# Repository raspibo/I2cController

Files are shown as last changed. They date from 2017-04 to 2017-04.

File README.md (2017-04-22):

# I2cController
Evolution of I2C_rotary_encoder, a board with lcd, rotary encoder, push buttons for general purpose input/output over I2C bus

Whit this board you can interact with a standard hardware equipment of rotary encoder, lcd display, push buttons over I2C, you can 
also mount a partial set of peripherals.

The code handle interrupt of pin change generated from MC23017 chip when event fire on buttons or rotary encoder.

# Use
Put portable dir under your arduino folder to use project specific libraries

# Typical Schematic



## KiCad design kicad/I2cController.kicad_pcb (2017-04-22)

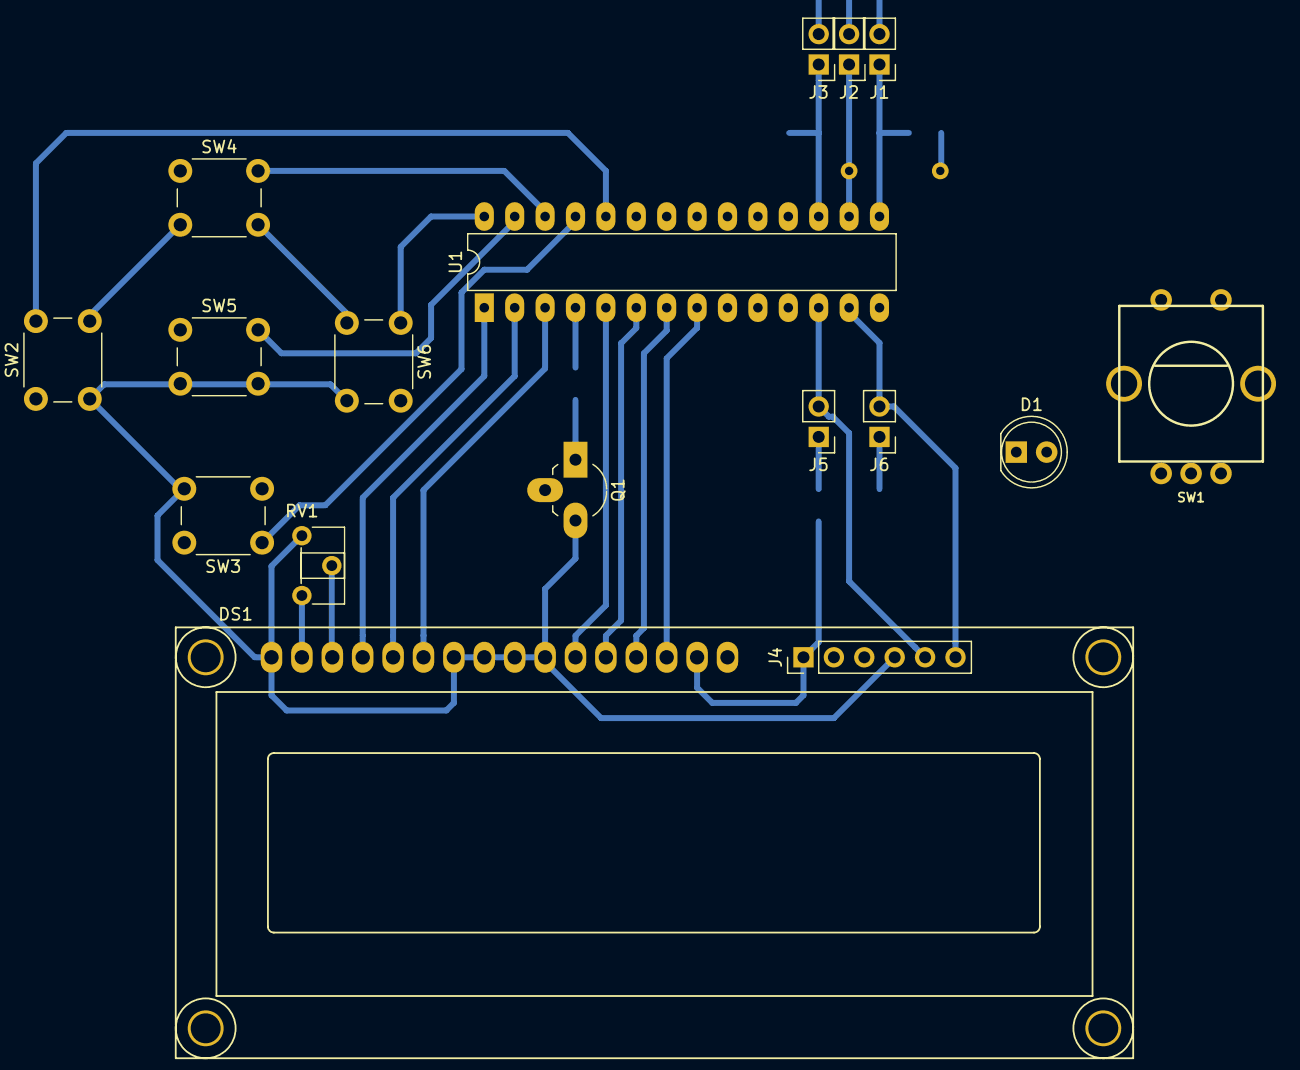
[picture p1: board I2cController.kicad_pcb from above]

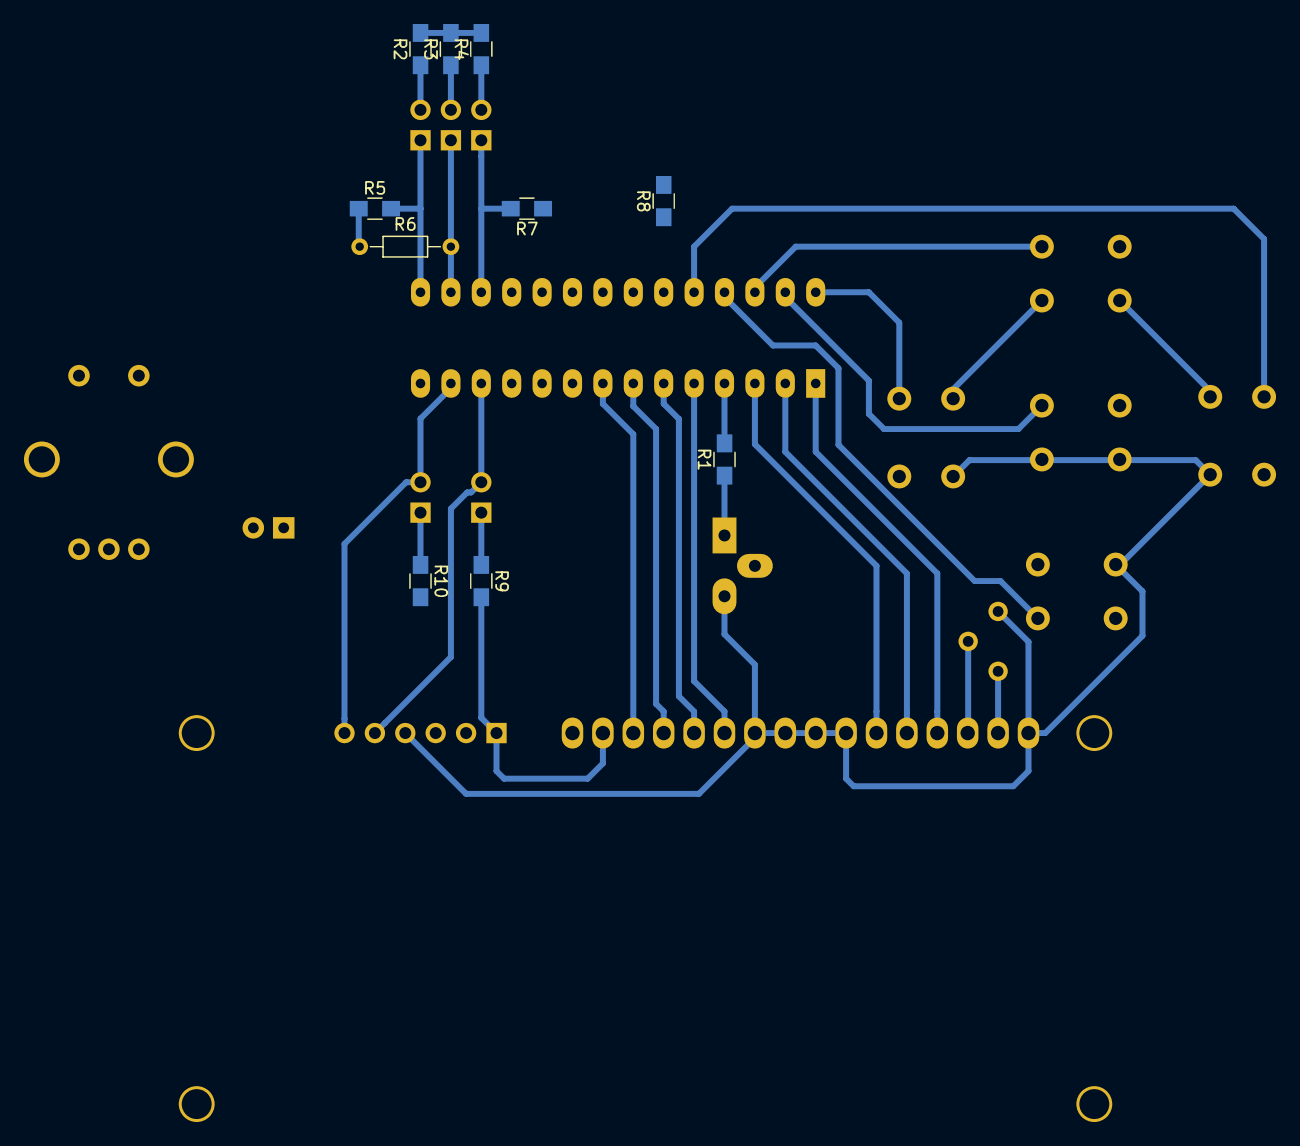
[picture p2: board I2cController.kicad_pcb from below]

Board: 2 copper layers, 27 parts (10 on the bottom side), 34 nets.

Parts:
D1: LED; LED_D5.0mm
DS1: LCD16X2; WC1602A
J1, J2, J3, J5, J6: CONN_02X01; Pin_Header_Straight_1x02_Pitch2.54mm
J4: CONN_01X06; Pin_Header_Straight_1x06_Pitch2.54mm
Q1: Q_NPN_BCE; TO-92_Rugged_Reverse
R1, R2, R3, R4, R5, R7, R8, R9, R10: R; R_0805_HandSoldering
R6: R; R_Axial_DIN0204_L3.6mm_D1.6mm_P7.62mm_Horizontal
RV1: POT; Potentiometer_Trimmer_ACP_CA6h_Vertical
SW1: Rotary_Encoder_Switch; SF-ROTARY-ENCODER
SW2, SW3, SW4, SW5, SW6: SW_Push; SW_PUSH_6mm_h7.3mm
U1: MCP23017; DIP-28_W7.62mm_LongPads

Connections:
GND: DS1.1, DS1.7, DS1.8, DS1.9, DS1.10, J4.4, Q1.3, R5.1, R6.1, R7.1, RV1.1, SW1.2, SW1.5, SW2.2, SW3.2, SW4.2, SW5.2, SW6.2, U1.10
L_D0: DS1.4, U1.1
L_D1: DS1.5, U1.2
L_D2: DS1.6, U1.3
L_D3: R1.2, U1.4
L_D4: DS1.11, U1.5
L_D5: DS1.12, U1.6
L_D6: DS1.13, U1.7
L_D7: DS1.14, U1.8
unnamed: D1.1, R8.1
unnamed: DS1.3, RV1.2
unnamed: DS1.16, Q1.2
unnamed: J1.1, R5.2, U1.15
unnamed: J1.2, R2.1
unnamed: J2.1, R6.2, U1.16
unnamed: J2.2, R3.1
unnamed: J3.1, R7.2, U1.17
unnamed: J3.2, R4.1
unnamed: J4.2, U1.18
unnamed: J4.3, R8.2, U1.20
unnamed: J5.1, R9.1
unnamed: J6.1, R10.1
unnamed: Q1.1, R1.1
unnamed: SW1.1, U1.22
unnamed: SW1.3, U1.21
unnamed: SW1.4, U1.23
unnamed: SW2.1, U1.24
unnamed: SW3.1, U1.25
unnamed: SW4.1, U1.26
unnamed: SW5.1, U1.27
unnamed: SW6.1, U1.28
SCL: J4.5, J5.2, U1.12
SDA: J4.6, J6.2, U1.13
VCC: D1.2, DS1.2, DS1.15, J4.1, R2.2, R3.2, R4.2, R9.2, R10.2, RV1.3, U1.9

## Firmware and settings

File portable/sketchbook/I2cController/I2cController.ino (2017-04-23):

/*
   From https://github.com/lincomatic/I2cControllerLib
   and http://blog.think3dprint3d.com/2012/12/mcp23017-i2c.html
 */

// include the library code:
#include <Wire.h>
#include <I2cController.h>

#define EN_A 0 // Encored scroll A0
#define EN_B 1 // Encoder scroll A1 
#define EN_C 2 // Encoder click  A2
#define BTN_NUM 5
#define BTN_1 3 // Single button A3
#define BTN_2 4 // Single button A4
#define BTN_3 5 // Single button A5
#define BTN_4 6 // Single button A6
#define BTN_5 7 // Single button A7

// Connect via i2c, default address #0 (A0-A2 not jumpered)
I2cControllerLib contr(0);
int encoderPos=0;
uint8_t clickButton;

uint8_t Pot;
char ActEnc, OldEnc;


// Interrupts from the MCP will be handled by this PIN on Arduino
byte arduinoIntPin = 3;
// ... and this interrupt vector
byte arduinoInterrupt = 1;

volatile boolean awakenByInterrupt = false;
unsigned long lastMillisInterrupt = 0;

void handleInterrupt() {

	detachInterrupt(arduinoInterrupt);
	if (millis()>lastMillisInterrupt+25) {
		//A    |¯¯|__|¯¯|__|¯
		//B  - __|¯¯|__|¯¯|__  +
		// Nel canale A pin D3 condensatore ceramico 103K 10nF
		uint8_t ActEnc=0;
		uint8_t intPin=contr.getLastInterruptPin();
		uint8_t valPin=contr.getLastInterruptPinValue();
		//Serial.print("intPin: ");
		//Serial.println(intPin);
		//Switch che  decide come gestire interrupt in base al pin che lo ha generato se A0 o A1 interpreta encoder altrimenti interpretazione come pulsante
		switch(intPin) {
			case EN_A:
			case EN_B:
				bitWrite(ActEnc, 0,contr.digitalRead(EN_A));
				bitWrite(ActEnc, 1,contr.digitalRead(EN_B));
				switch(ActEnc) {
					case 0: //00
						if(OldEnc==2) Pot++;  //10
						if(OldEnc==1) Pot--;  //01
						break;
					case 1: //01
						if(OldEnc==0) Pot++;  //00
						if(OldEnc==3) Pot--;  //11
						break;
					case 2: //10
						if(OldEnc==3) Pot++;  //11
						if(OldEnc==0) Pot--;  //00
						break;
					case 3: // 11
						if(OldEnc==1) Pot++;  //01
						if(OldEnc==2) Pot--;  //10
						break;
				}
				OldEnc=ActEnc;
				Serial.print("Pot: ");
				Serial.println(Pot);
				break;
			case EN_C:
				Serial.println("click");
				break;
			default:
				Serial.print("Button: A");
				Serial.println(intPin);
				break;
		}
	}



	lastMillisInterrupt=millis();
	cleanInterrupts();
	//we set callback for the arduino INT handler.
	attachInterrupt(arduinoInterrupt, intCallBack, FALLING);
}


void intCallBack() {
	awakenByInterrupt = true;
}

void cleanInterrupts() {
	EIFR = 0x01;
	awakenByInterrupt = false;
}

void setup() {
	Serial.begin(115200);
	Serial.println("Startup");
	contr.setMCPType(LTI_TYPE_MCP23017); 
	// set up the LCD's number of rows and columns:
	contr.begin(16, 2);
	// Print a message to the LCD.
	contr.print("hello, world!");
	for (int count = 0; count < 16; count++) {
		contr.pinMode(count, OUTPUT);
	}
	contr.setupEncoder(EN_A,EN_B,EN_C); // Encoder setup 
//	contr.setIntBtn(BTN_1);                 // Single button setup
	//contr.setupInterruptPin(BTN_1, FALLING); //Use this if you want receive continuos interrupt on button pressed. Useful ??
        uint8_t btnCross[BTN_NUM] = { BTN_1, BTN_2, BTN_3, BTN_4, BTN_5}; // Five button on cross disposition, setup function
        contr.setIntCross(btnCross, BTN_NUM);
	attachInterrupt(arduinoInterrupt, intCallBack, FALLING);

}

void loop() {
	// set the cursor to column 0, line 1
	// (note: line 1 is the second row, since counting begins with 0):
	contr.setCursor(0, 1);
	// print the number of seconds since reset:
	contr.print(millis()/1000);

	//contr.setBacklight(HIGH);
	//delay(500);
	//contr.setBacklight(LOW);
	//delay(500);

	if (awakenByInterrupt) handleInterrupt();
	delay(30);
}

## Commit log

2017-04-20 Add kicad schematic
    [I2cController.kicad_pcb, I2cController.sch]
2017-04-20 remove old schematic
2017-04-21 OK encoder sequence
2017-04-22 Encoder OK, buttons OK
